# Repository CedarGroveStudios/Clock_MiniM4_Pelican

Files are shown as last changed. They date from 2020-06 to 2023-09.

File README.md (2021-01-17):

# Clock_MiniM4_Pelican (Clock Minima)
## _A minimal but large clock in a Pelican 1040 Micro Case with CircuitPython_

The Clock_MiniM4 is an RTC-based minimal LED display clock implementation inspired by John Park's MetroMinimalist Clock design. The clock uses custom CircuitPython libraries __CedarGroveStudios/Unit_Converter__ for automatic Daylight Saving Time (DTS) and __CedarGroveStudios/Clock_Builder__ for display and user interface functions.

Caution: Under elevated temperature conditions, the sealed Pelican case may not sufficiently dissipate the heat from the clock electronics. A test of the internal operating temperature measured 80F (27C) when interior room temperature was nominally 77F (25C). If the clock will be operated in warmer environments, it is recommended that some holes be drilled into the case to allow air flow.

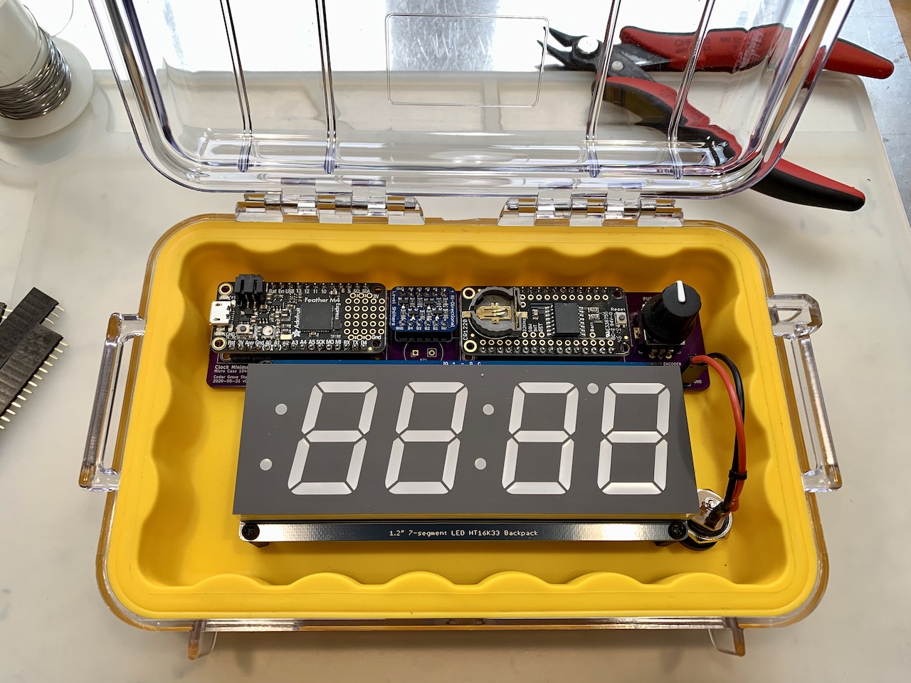
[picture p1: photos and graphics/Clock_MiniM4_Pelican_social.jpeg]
Clock_MiniM4

Photo 1. During assembly.

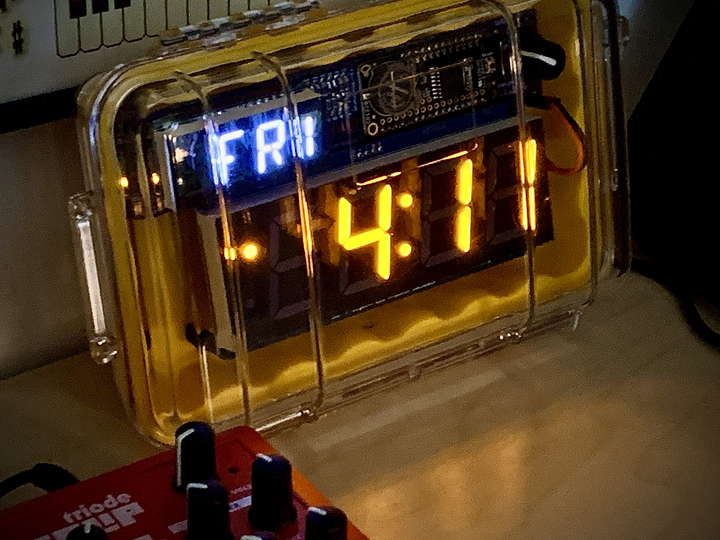
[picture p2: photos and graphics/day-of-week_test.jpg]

Photo 2. Test of auxilliary day-of-week display.



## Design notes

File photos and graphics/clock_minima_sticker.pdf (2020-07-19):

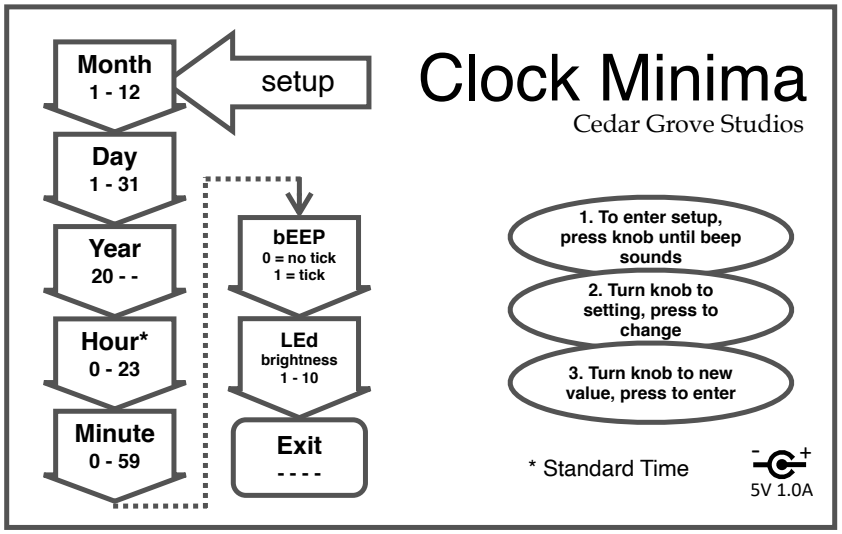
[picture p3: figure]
Clock Minima; Cedar Grove Studios; 1. To enter setup, press knob until beep sounds; 2. Turn knob to setting, press to change; 3. Turn knob to new value, press to enter; setup; Exit; LEd brightness 1 - 10; bEEP 0 = no tick 1 = tick; Minute 0 - 59; Hour*; Year 20 - -; Day; Month; * Standard Time

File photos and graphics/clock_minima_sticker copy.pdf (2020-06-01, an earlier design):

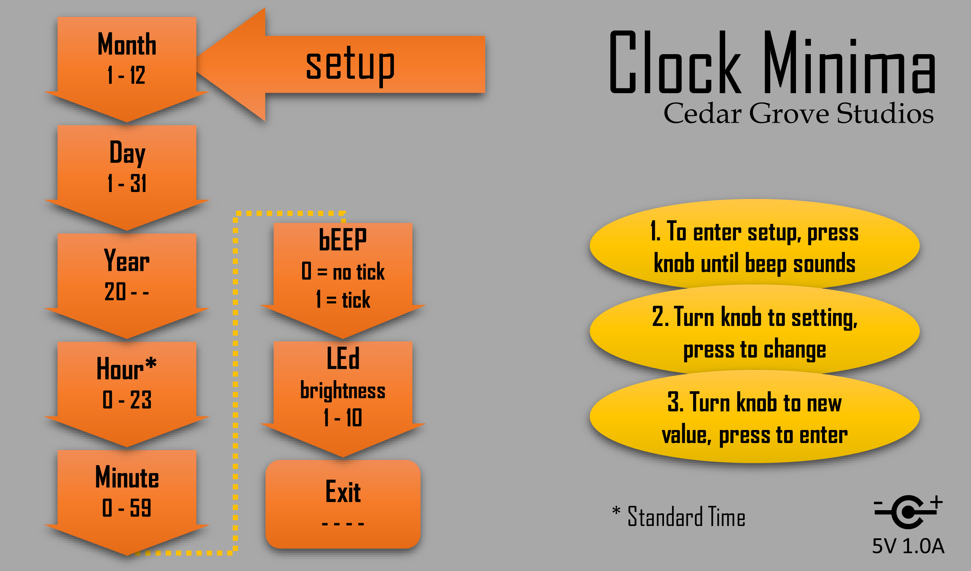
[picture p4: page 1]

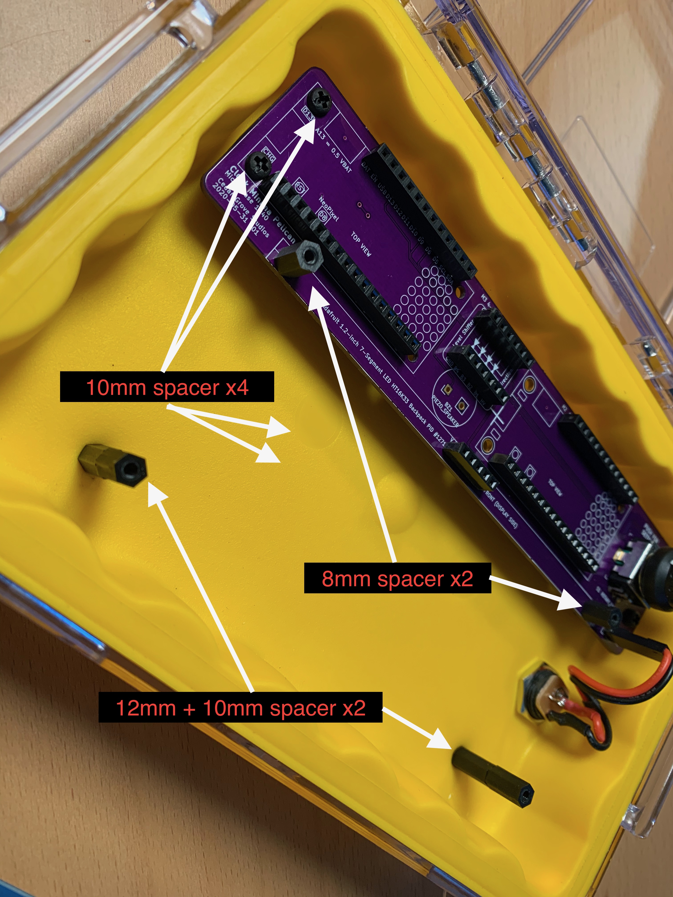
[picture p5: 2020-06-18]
photos and graphics/IMG_0296 - annotated.jpg

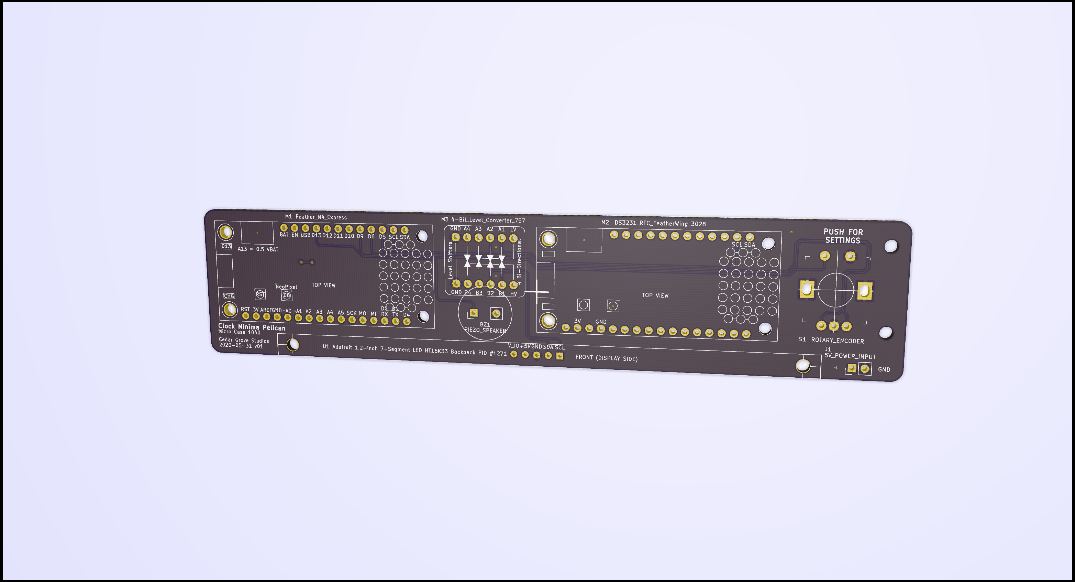
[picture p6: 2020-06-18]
PCB/Clock_MiniM4_Pelican.png

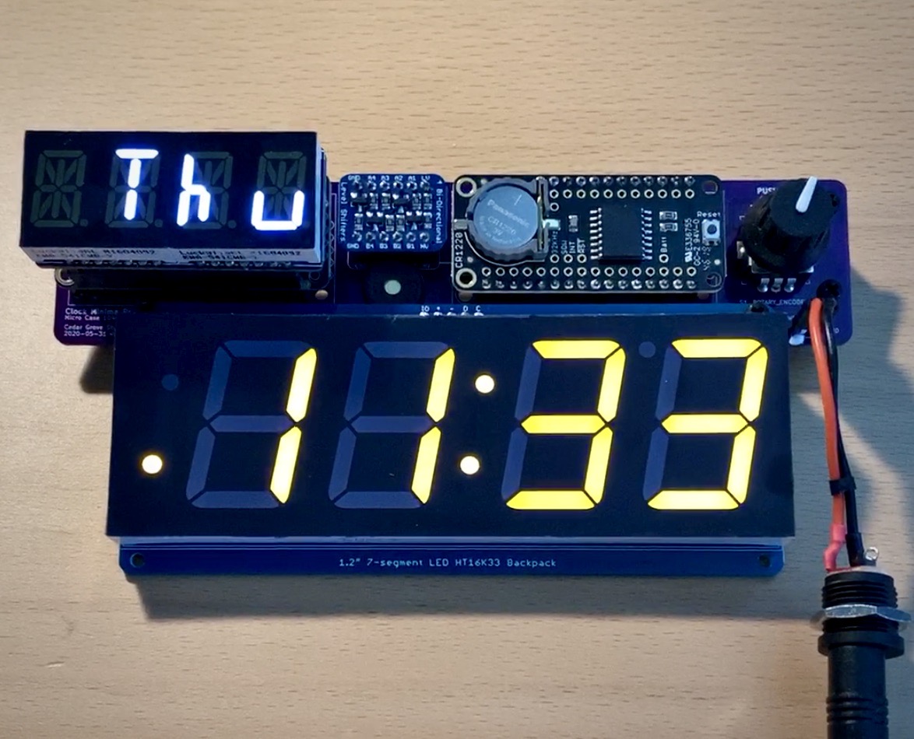
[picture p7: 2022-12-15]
photos and graphics/Screen Shot 2020-07-23 at 3.09.02 PM.jpeg

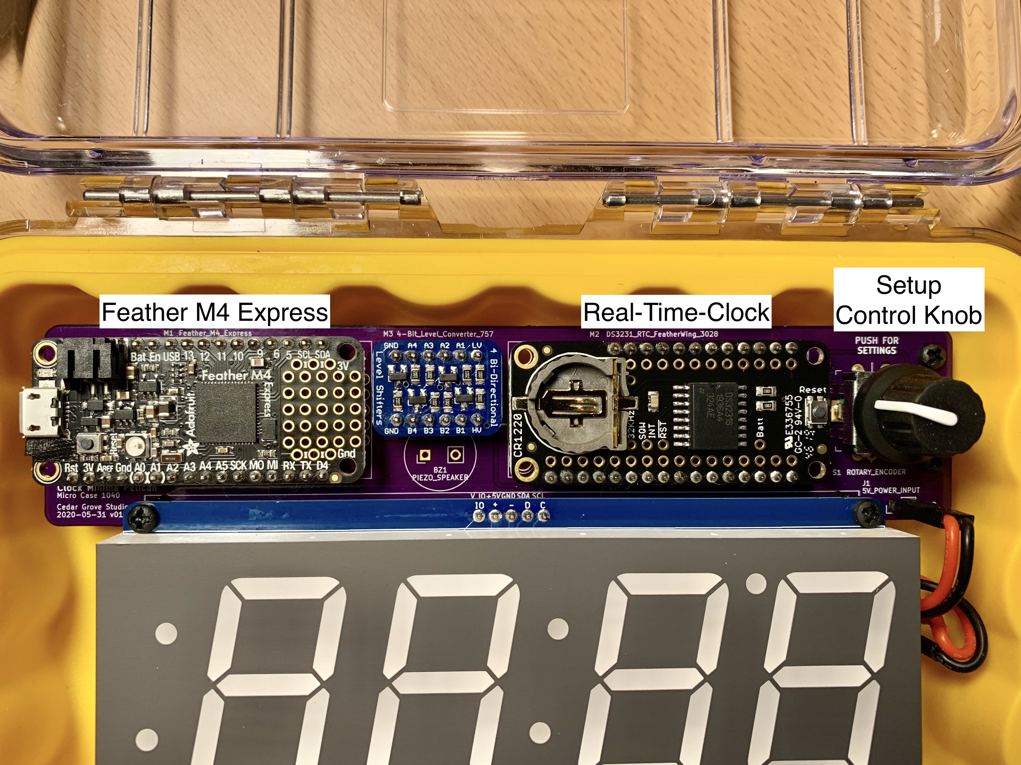
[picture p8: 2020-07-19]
photos and graphics/IMG_0295 annotated.jpg

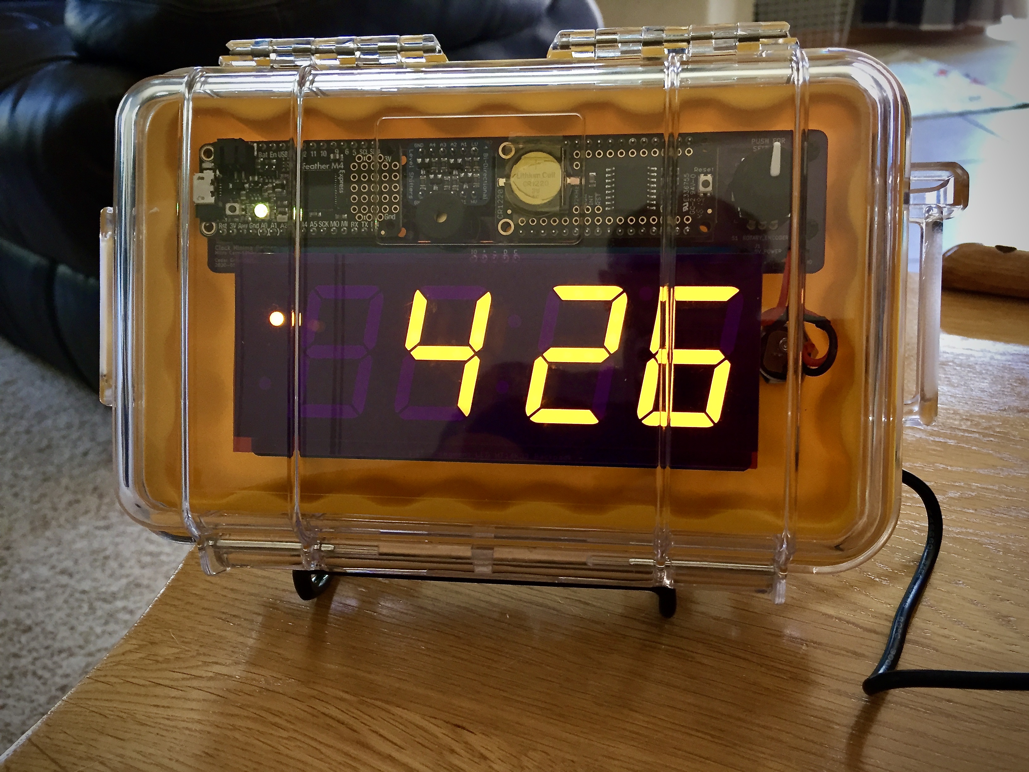
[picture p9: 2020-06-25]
photos and graphics/Clock_MiniM4_Pelican_Spokane.jpeg

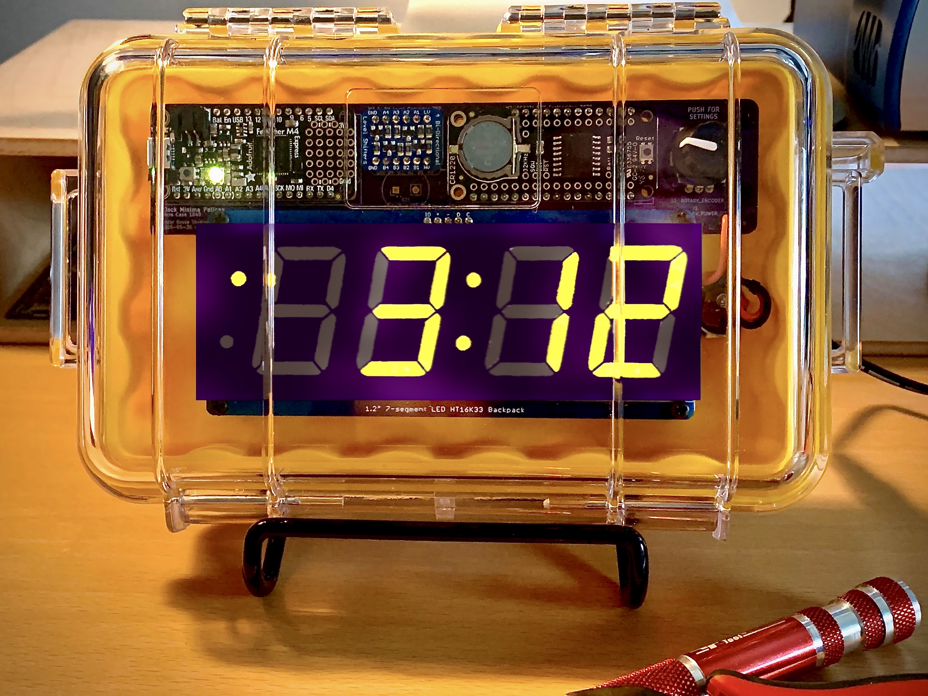
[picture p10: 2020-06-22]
photos and graphics/Clock_MiniM4_Pelican_glamour.jpeg

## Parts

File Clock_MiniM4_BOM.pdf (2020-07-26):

### Bill Of Materials

Qty | Designation | Description | Adafruit | | Digikey | Notes
1 | M1 | Feather M4 Express | PID 3857 | https://www.adafruit.com/product/3857 (https://www.adafruit.com/product/3857) | https://www.digikey.com/products/en?mpart=3857&v=1528 (https://www.digikey.com/products/en?mpart=3857&v=1528)
1 | M2 | DS3231 Precision RTC FeatherWing | PID 3028 | https://www.adafruit.com/product/3028 (https://www.adafruit.com/product/3028) | https://www.digikey.com/products/en?mpart=3028&v=1528 (https://www.digikey.com/products/en?mpart=3028&v=1528) | CR1220 battery: https://www.adafruit.com/products/380 | https://www.digikey.com/product-detail/en/panasonic-bsg/CR1220/P033-ND/269740 (https://www.digikey.com/product-detail/en/panasonic-bsg/CR1220/P033-ND/269740)
1 | M3 | 4-channel I2C-safe Bi-directional Logic Level Converter - BSS138 | PID 757 | https://www.adafruit.com/product/757 (https://www.adafruit.com/product/757) | https://www.digikey.com/products/en?mpart=757&v=1528 (https://www.digikey.com/products/en?mpart=757&v=1528)
1 | S1 | Rotary Encoder | PID 377 | https://www.adafruit.com/product/377 (https://www.adafruit.com/product/377) | https://www.digikey.com/products/en?mpart=377&v=1528 (https://www.digikey.com/products/en?mpart=377&v=1528)
1 | BZ1 | Piezo Buzzer - PS1240 | PID 160 | https://www.adafruit.com/product/160 (https://www.adafruit.com/product/160) | https://www.digikey.com/product-detail/en/tdk-corporation/PS1240P02CT3/445-5229-1-ND/2179635 (https://www.digikey.com/product-detail/en/tdk-corporation/PS1240P02CT3/445-5229-1-ND/2179635) | Alternate: https://www.digikey.com/product-detail/en/tdk-corporation/PS1240P02BT/445-2525-1-ND/935930 (https://www.digikey.com/product-detail/en/tdk-corporation/PS1240P02BT/445-2525-1-ND/935930)
1 | U1 | Adafruit 1.2" 4-Digit 7-Segment Display w/I2C Backpack - Yellow | PID 1269 | https://www.adafruit.com/product/1269 (https://www.adafruit.com/product/1269) | https://www.digikey.com/products/en?mpart=1269&v=1528 (https://www.digikey.com/products/en?mpart=1269&v=1528) | LED display with 5-volt power and data interface (I2C)
1 | | Panel Mount 2.1mm DC barrel jack | PID 610 | https://www.adafruit.com/product/610 (https://www.adafruit.com/product/610) | https://www.digikey.com/product-detail/en/schurter-inc/4840-2200/486-3380-ND/1212406 (https://www.digikey.com/product-detail/en/schurter-inc/4840-2200/486-3380-ND/1212406) | 5v power input jack, 2.1mm
2 | | Short Pin Feather Headers | PID 3002 | https://www.adafruit.com/product/3002 (https://www.adafruit.com/product/3002) | | Pin connectors for Feather M4 and RTC FeatherWing
2 | | Short Receptacle Feather Headers | PID 2940 | https://www.adafruit.com/product/2940 (https://www.adafruit.com/product/2940) | | Pin connectors for Feather M4 and RTC Feather Wing
1 | | 36-pin Short Pin Headers | PID 3009 | https://www.adafruit.com/product/3009 (https://www.adafruit.com/product/3009) | | Pin connectors for Level Converter and LED Display
1 | | 36-pin Short Receptacle Headers | PID 3008 | https://www.adafruit.com/product/3008 (https://www.adafruit.com/product/3008) | | Pin connectors for Level Converter and LED Display
1 Black Nylon Screw and Stand-off Set | | – M2.5 Thread | PID 3299 | https://www.adafruit.com/product/3299 (https://www.adafruit.com/product/3299) | | M2.5 screws and standoffs for mounting PCB and display
1 Pelican 1040 Micro Case, Yellow- | | Clear | | | | https://www.amazon.com/Pelican-1040-Micro-Yellow-Clear/dp/B00152PF4I/ref=psdc_3406401_t2_B0029Q7A1K (https://www.amazon.com/Pelican-1040-Micro-Yellow-Clear/dp/B00152PF4I/ref=psdc_3406401_t2_B0029Q7A1K)
1 | | PCB | | | | OSH Park: https://oshpark.com/shared_projects/wLMeJjED (https://oshpark.com/shared_projects/wLMeJjED)
1 5V 2A (2000mA) switching power | | supply - UL Listed | PID 276 | https://www.adafruit.com/product/276 (https://www.adafruit.com/product/276) | https://www.digikey.com/product-detail/en/tensility-international-corp/16-00066/839-1669-ND/10324415 (https://www.digikey.com/product-detail/en/tensility-international-corp/16-00066/839-1669-ND/10324415) | Wall wart with 2.1mm center-positive plug
1 Adjustable Bent-Wire Stand - up to | | 7" Tablets and Small Screens | PID 1679 | https://www.adafruit.com/product/1679 (https://www.adafruit.com/product/1679) | https://www.digikey.com/products/en?mpart=1679&v=1528 (https://www.digikey.com/products/en?mpart=1679&v=1528)

1

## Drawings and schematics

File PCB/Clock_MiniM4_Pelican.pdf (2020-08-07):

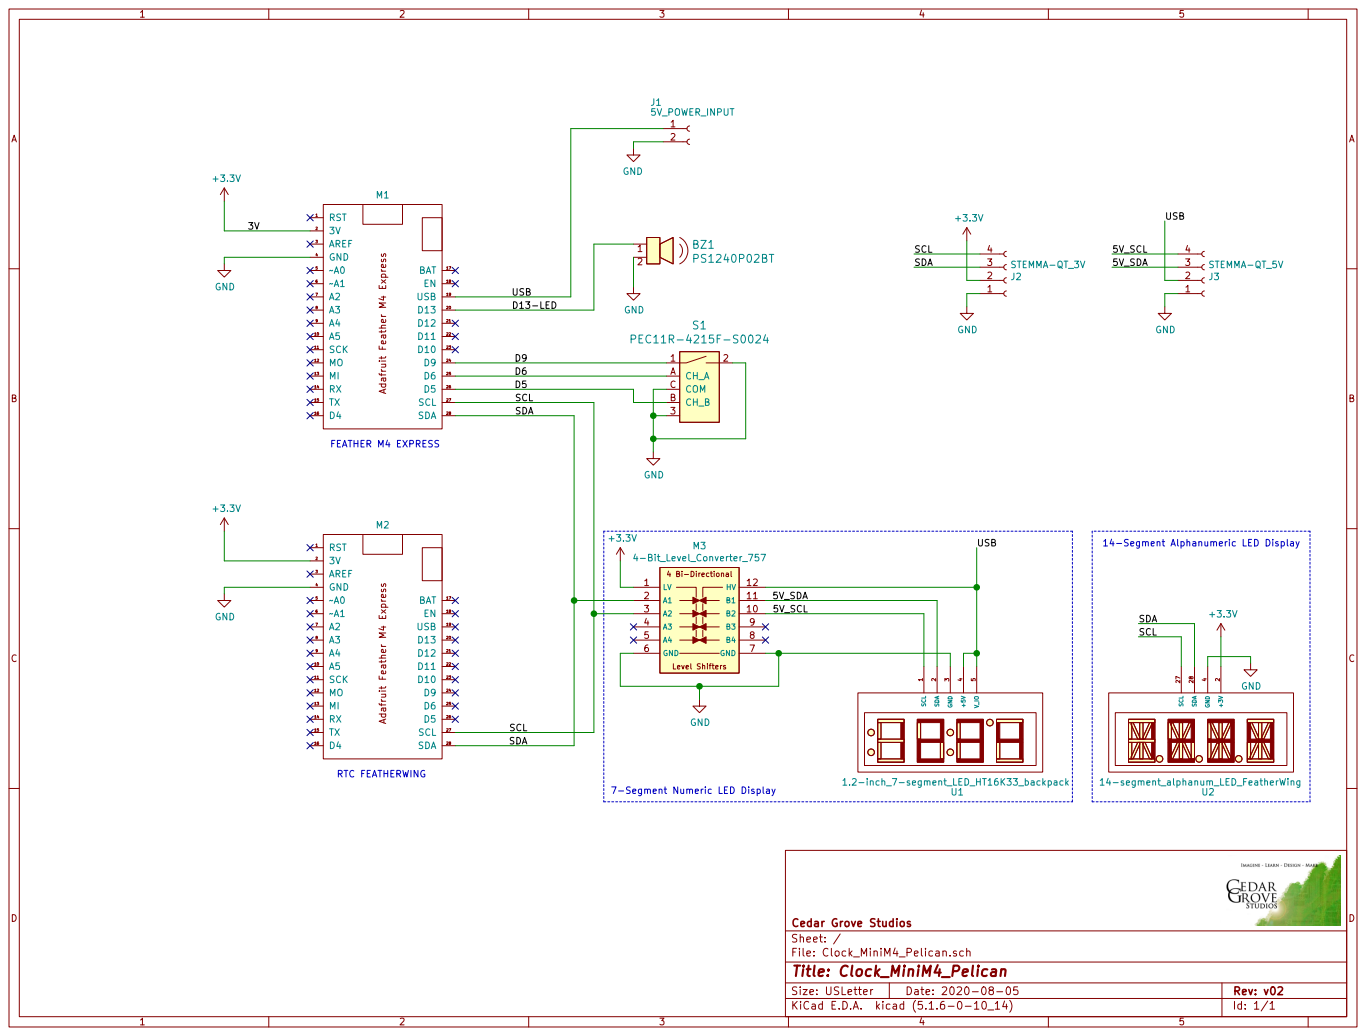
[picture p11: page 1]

7-Segment Numeric LED Display FEATHER M4 EXPRESS RTC FEATHERWING

14-Segment Alphanumeric LED Display

4 Bi-Directional Level Shifters LV 1

File: Clock_MiniM4_Pelican.sch Sheet: / Cedar Grove Studios

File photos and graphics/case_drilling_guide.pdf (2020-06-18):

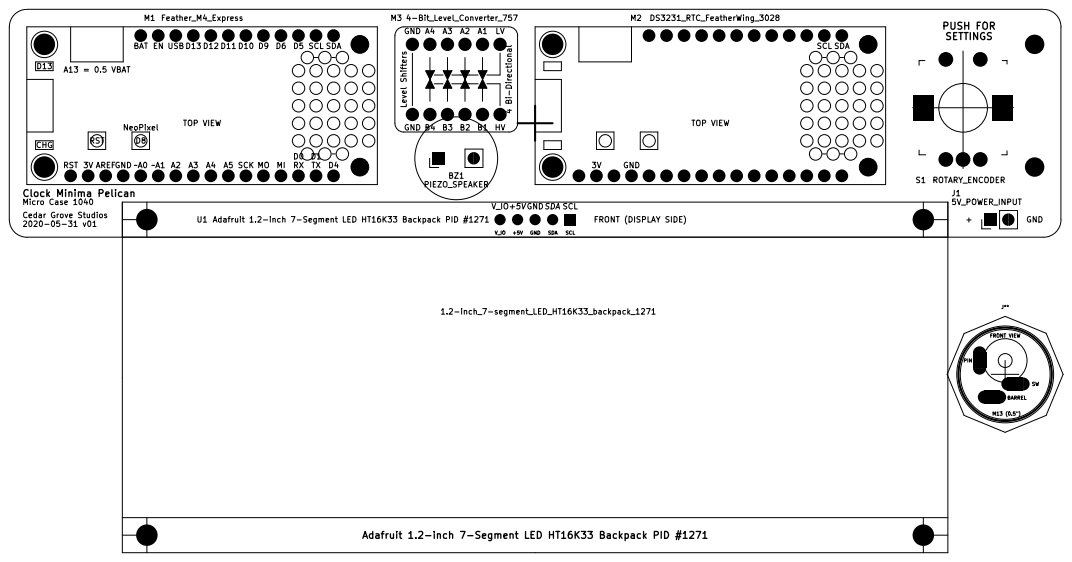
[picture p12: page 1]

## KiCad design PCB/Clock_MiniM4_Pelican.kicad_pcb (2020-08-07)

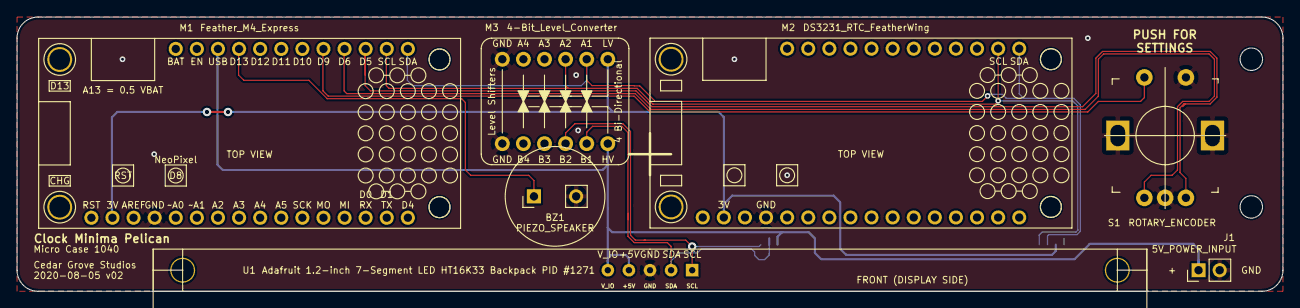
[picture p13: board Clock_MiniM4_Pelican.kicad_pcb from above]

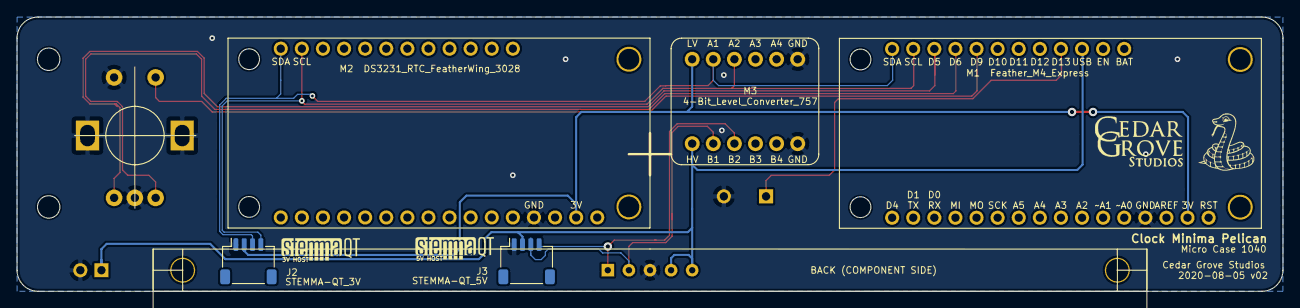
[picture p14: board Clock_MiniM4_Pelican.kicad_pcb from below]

Board: 2 copper layers, 152.4 x 33.0 mm, 10 parts (2 on the bottom side), 11 nets.

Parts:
BZ1: PIEZO_SPEAKER; Socket_Strip_Straight_1x02_Pitch2.54mm
J1: 5V_POWER_INPUT; PinHeader_1x02_P2.54mm_Vertical
J2: STEMMA-QT_3V; JST_SH_SM04B-SRSS-TB_1x04-1MP_P1.00mm_Horizontal
J3: STEMMA-QT_5V; JST_SH_SM04B-SRSS-TB_1x04-1MP_P1.00mm_Horizontal
J**: 2.1mm_THT_DC_panel_power_conn_610
M1: Feather_M4_Express; Adafruit_Feather_M4_Express
M2: DS3231_RTC_FeatherWing; Adafruit_Feather_M4_Express
M3: 4-Bit_Level_Converter; 4-Bit_Level_Converter_757
S1: ROTARY_ENCODER; Rotary_Encoder_Switched_PEC11R_mntg_hole
U1: 1.2-inch_7-segment_LED_HT16K33_backpack

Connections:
+3V3: J2.2, M1.2, M2.2, M3.1
/5V_SCL: J3.4, M3.10, U1.1
/5V_SDA: J3.3, M3.11, U1.2
/D5: M1.26, S1.B
/D6: M1.25, S1.A
/D9: M1.24, S1.1
/D13-LED: BZ1.1, M1.20
/SCL: J2.4, M1.27, M2.27, M3.3
/SDA: J2.3, M1.28, M2.28, M3.2
/USB: J1.1, J3.2, M1.19, M3.12, U1.4, U1.5
GND: BZ1.2, J1.2, J2.1, J3.1, M1.4, M2.4, M3.6, M3.7, S1.2, S1.3, S1.C, U1.3

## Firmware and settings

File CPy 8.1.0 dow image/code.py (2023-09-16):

# clock_miniM4_bigLED.py  2020-07-05_v01)
# Cedar Grove Studios
# for "BIG" 2.1-inch LED display and rotary encoder time setter
# and 14x4 display
# uses cedargrove_unit_converter library
# uses cedargrove_clock_builder library (display, set_time, chime)

import time
import board
import neopixel as neo  # Feather M4
from   simpleio import map_range, tone
import adafruit_ds3231
from   analogio import AnalogIn
from   cedargrove_unit_converter.chronos              import adjust_dst
from   cedargrove_clock_builder.repl_display          import ReplDisplay
from   cedargrove_clock_builder.bigled_7x4_display    import BigLed7x4Display   # 7-segment LED
from   cedargrove_clock_builder.led_14x4_display_dow  import Led14x4DisplayDOW  # 14-segment LED

i2c = board.I2C()
ds3231 = adafruit_ds3231.DS3231(i2c)

# Feather M4 battery monitor and piezo
batt = AnalogIn(board.VOLTAGE_MONITOR)

# Feather M4 NeoPixel, purple start-up indicator
pixel = neo.NeoPixel(board.NEOPIXEL,1, brightness=0.01, auto_write=False)
pixel[0] = (200, 0, 200)
pixel.write()
time.sleep(0.1)

print("Battery: {:01.2f} volts".format((batt.value / 65520) * 6.6))

from Clock_Minima_Pelican_config import *
"""
# Typical contents of config file:
### CONFIGURATION ###
clock_display  = ["big_led", "repl"]  # List of active display(s)
clock_zone     = "Pacific"  # Name of local time zone
clock_24_hour  = False      # 24-hour clock = True; 12-hour AM/PM = False
clock_auto_dst = True       # Automatic US DST = True
clock_sound    = False      # Sound is active = True
clock_tick     = True       # One-second tick sound
clock_bright   = 1.0        # Display brightness; 0 (low) to 1.0 (high)
"""

### Instatiate displays

#  4-digit 7-segment LED display
led_disp  = BigLed7x4Display(clock_zone, clock_24_hour, clock_auto_dst,
                          clock_sound, clock_bright, debug=False, address=0x70)

#  4-digit 14-segment LED alphanumeric display
alpha_led_disp  = Led14x4DisplayDOW(clock_zone, clock_24_hour, clock_auto_dst,
                          clock_sound, clock_bright, debug=False, address=0x71)

#  REPL display
repl_disp = ReplDisplay(clock_zone, clock_24_hour, clock_auto_dst,
                        clock_sound, debug=False)

### Instatiate time setter
# (none)

### Instatiate chimes
# (none)

### HELPERS ###

# Manually set time upon RTC power failure
if ds3231.lost_power:
    print("--RTC POWER FAILURE--")
    # Set time with REPL
    # ds3231.datetime = repl_disp.set_datetime()

    # Set time with LED with rotary encoder
    led_disp.alert("----")

min_flag = half_flag = hour_flag = False

# initiate display contents

# Check datetime and adjust if DST
if clock_auto_dst:             # read the RTC and adjust for DST
    current, is_dst = adjust_dst(ds3231.datetime)
else:
    current = ds3231.datetime  # otherwise, just read the RTC
    is_dst = False

if "led" or "big_led" in clock_display:
    if "led" in clock_display:
        led_disp.message = "CG MiniM4L CLOCK"
    led_disp.dst = is_dst
    led_disp.show(current)
    alpha_led_disp.show_day_of_week(current)

while True:
    # Check datetime and adjust if DST
    if clock_auto_dst:             # read the RTC and adjust for DST
        current, is_dst = adjust_dst(ds3231.datetime)
    else:
        current = ds3231.datetime  # otherwise, just read the RTC
        is_dst = False

    # update REPL display
    if "repl" in clock_display:
        repl_disp.dst = is_dst
        repl_disp.show(current)

    # update led display
    if "led" or "big_led" in clock_display:
        led_disp.colon  = not led_disp.colon

        # Check to see if time was set
        new_xst_datetime, clock_sound, update_flag = led_disp.set_datetime(ds3231.datetime)
        if update_flag:  # If so, update RTC Std Time with new datetime
           ds3231.datetime = new_xst_datetime
           print("RTC time was set")

        led_disp.dst    = is_dst
        led_disp.show(current)  # refresh LED display

        # Refresh FeatherM4 NeoPixel to show "second hand"
        r = int(map_range(current.tm_sec, 0, 45, 255, 100))
        g = int(map_range(current.tm_sec, 15, 59, 100, 255))
        b = int(map_range(current.tm_sec, 55, 59, 100, 255))
        pixel[0] = (r, g, b)
        pixel.write()

    # play tick sound
    if "led" or "big_led" in clock_display:
        if clock_sound and clock_tick:
            led_disp.tick()

    # Do something every minute
    if current.tm_sec == 0 and not min_flag:
        # do something here
        print("every MIN")

        print("Battery: {:01.2f} volts".format((batt.value / 65520) * 6.6))

        # Display date on LED display
        if "led" or "big_led" in clock_display:
            led_disp.dst = is_dst
            alpha_led_disp.brightness = led_disp.brightness
            alpha_led_disp.show_day_of_week(current)
            led_disp.show(current, date=True)

        min_flag = True
    elif current.tm_sec > 0:
        min_flag = False

    # Do something every half-hour
    if current.tm_min == 30 and not half_flag:
        # do something here
        print("every HALF")
        half_flag = True
    elif current.tm_min > 30:
        half_flag = False

    # Do something every hour
    if current.tm_min == 0 and not hour_flag:
        # do something here
        print("every HOUR")
        hour_flag = True
    elif current.tm_min > 0:
        hour_flag = False

    # wait a second before looping
    prev_sec = current.tm_sec
    while current.tm_sec == prev_sec:  # wait a second before looping
        current = ds3231.datetime

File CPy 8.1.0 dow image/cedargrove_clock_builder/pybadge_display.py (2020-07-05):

# pybadge_display.py
# 2020-03-21 Cedar Grove Studios

import time
import board
import displayio
from   adafruit_display_text.label import Label
from   adafruit_bitmap_font        import bitmap_font
import adafruit_imageload
from   adafruit_pybadger import pybadger
from   simpleio                    import map_range

class PyBadgeDisplay:

    def __init__(self, timezone="Pacific", hour_24=False, auto_dst=True,
                 sound=False, brightness=1.0, debug=False):
        # Input parameters
        self._timezone   = timezone
        self._hour_24_12 = hour_24
        self._dst        = False
        self._auto_dst   = auto_dst
        self._sound      = sound
        self._brightness = brightness

        # Other parameters
        self._message     = "PyBadge Clock"
        self._colon       = True
        self._batt_level  = 0   # Default battery level
        self._label_edits = []  # label edit attributes
        self._label_restore_color = []  # for restoring text color values

        self._weekday = ["Mon", "Tue", "Wed", "Thu", "Fri", "Sat", "Sun"]
        self._month   = ["Jan", "Feb", "Mar", "Apr", "May", "Jun", "Jul", "Aug",
                         "Sep", "Oct", "Nov", "Dec"]

        # Load the text font from the fonts folder
        self._font_0 = bitmap_font.load_font("/fonts/OpenSans-9.bdf")
        self._font_1 = bitmap_font.load_font("/fonts/Helvetica-Bold-36.bdf")

        # Instantiate PyBadger instance
        self.panel = pybadger
        self.panel._neopixels.brightness = 0.1  # Set default NeoPixel brightness
        self.panel.pixels.fill(0x000000)        # Clear all NeoPixels
        self.panel.play_tone(440, 0.1)          # A4 welcome tone

        # The board's integral display size and element size
        WIDTH  = board.DISPLAY.width   # 160 for PyGamer and PyBadge
        HEIGHT = board.DISPLAY.height  # 128 for PyGamer and PyBadge
        ELEMENT_SIZE = WIDTH // 4  # Size of element_grid blocks in pixels
        board.DISPLAY.brightness = self._brightness

        # Default colors
        self.BLACK   = 0x000000
        self.RED     = 0xFF0000
        self.ORANGE  = 0xFF8811
        self.YELLOW  = 0xFFFF00
        self.GREEN   = 0x00FF00
        self.CYAN    = 0x00FFFF
        self.BLUE    = 0x0000FF
        self.LT_BLUE = 0x000044
        self.VIOLET  = 0x9900FF
        self.DK_VIO  = 0x110022
        self.WHITE   = 0xFFFFFF
        self.GRAY    = 0x444455

        ### Define the display group ###
        self._image_group = displayio.Group(max_size=15)

        # Create a background color fill layer; image_group[0]
        self._color_bitmap = displayio.Bitmap(WIDTH, HEIGHT, 1)
        self._color_palette = displayio.Palette(1)
        self._color_palette[0] = self.DK_VIO
        self._background = displayio.TileGrid(self._color_bitmap,
                                              pixel_shader=self._color_palette,
                                              x=0, y=0)
        self._image_group.append(self._background)
        self._label_restore_color.append(self.DK_VIO)
        self._label_edits.append(None)

        # Battery indicator tile grid; image_group[1]
        self._sprite_sheet, self._palette = adafruit_imageload.load("/cedargrove_clock_builder/batt_sprite_sheet.bmp",
                                                                    bitmap=displayio.Bitmap,
                                                                    palette=displayio.Palette)
        self._batt_icon = displayio.TileGrid(self._sprite_sheet,
                                             pixel_shader=self._palette,
                                             width = 1, height = 1,
                                             tile_width = 16, tile_height = 16)
        self._batt_icon.x = WIDTH - 16
        self._batt_icon.y = 1
        self._image_group.append(self._batt_icon)
        self._label_restore_color.append(self.BLACK)
        self._label_edits.append(None)

        ### Define labels and values using element grid coordinates
        # Colon; image_group[2]
        self._clock_digits_colon = Label(self._font_1, text=":",
                                         color=self.WHITE, max_glyphs=1)
        self._clock_digits_colon.x = 62
        self._clock_digits_colon.y = (HEIGHT // 2) + 10 - 3
        self._image_group.append(self._clock_digits_colon)
        self._label_restore_color.append(self._clock_digits_colon.color)
        self._label_edits.append(None)

        # Weekday; image_group[3]
        self._clock_wday = Label(self._font_0, text="---",
                                 color=self.YELLOW, max_glyphs=3)
        self._clock_wday.x = 21
        self._clock_wday.y = 40
        self._image_group.append(self._clock_wday)
        self._label_restore_color.append(self._clock_wday.color)
        self._label_edits.append(None)

        # Comma for Month Day (date); image_group[4]
        self._clock_comma = Label(self._font_0, text=",",
                                  color=self.YELLOW, max_glyphs=1)
        self._clock_comma.x = 99
        self._clock_comma.y = 40
        self._image_group.append(self._clock_comma)
        self._label_restore_color.append(self._clock_comma.color)
        self._label_edits.append(None)

        # AM/PM indicator; image_group[5]
        self._clock_ampm = Label(self._font_0, text="--",
                                 color=self.WHITE, max_glyphs=2)
        self._clock_ampm.x = 120
        self._clock_ampm.y = (HEIGHT // 2) + 10 - 8
        self._image_group.append(self._clock_ampm)
        self._label_restore_color.append(self._clock_ampm.color)
        self._label_edits.append(None)

        # Time Zone indicator; image_group[6]
        self._clock_dst = Label(self._font_0, text="---",
                                color=self.VIOLET, max_glyphs=3)
        self._clock_dst.x = 120
        self._clock_dst.y = (HEIGHT // 2) + 10 + 8
        self._image_group.append(self._clock_dst)
        self._label_restore_color.append(self._clock_dst.color)
        self._label_edits.append(None)

        # Sound indicator; image_group[7]
        self._clock_sound = Label(self._font_0, text="-----",
                                  color=self.VIOLET, max_glyphs=5)
        self._clock_sound.x = 5
        self._clock_sound.y = HEIGHT - 8
        self._image_group.append(self._clock_sound)
        self._label_restore_color.append(self._clock_sound.color)
        self._label_edits.append(("boolean", 0, 1))

        # Automatic DST indicator; image_group[8]
        self._clock_auto_dst = Label(self._font_0, text="-------",
                                     color=self.VIOLET, max_glyphs=7)
        self._clock_auto_dst.x = 104
        self._clock_auto_dst.y = HEIGHT - 8
        self._image_group.append(self._clock_auto_dst)
        self._label_restore_color.append(self._clock_auto_dst.color)
        self._label_edits.append(("boolean", 0 , 1))
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

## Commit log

2020-06-01 initial repo load
    [Clock_MiniM4_Pelican-B_Cu.gbl, Clock_MiniM4_Pelican-B_Mask.gbs, Clock_MiniM4_Pelican-B_Paste.gbp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]
2020-06-02 update PCB design
    [Clock_MiniM4_Pelican-B_Cu.gbl, Clock_MiniM4_Pelican-B_Mask.gbs, Clock_MiniM4_Pelican-B_Paste.gbp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]
2020-06-04 update schematic drawing
    [Clock_MiniM4_Pelican.sch]
2020-06-18 update BOM
2020-07-25 update PCB; display bright in param file
    [Clock_MiniM4_Pelican.kicad_pcb, Clock_MiniM4_Pelican.sch]
2020-07-26 update CPy 5.3 image and BOM
2020-08-05 Update new PCB design - fix STEMMA-QT pinout
    [Clock_MiniM4_Pelican-B_Cu.gbl, Clock_MiniM4_Pelican-B_Mask.gbs, Clock_MiniM4_Pelican-B_Paste.gbp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]
2020-08-07 update pcb
    [Clock_MiniM4_Pelican-B_Cu.gbl, Clock_MiniM4_Pelican-B_Mask.gbs, Clock_MiniM4_Pelican-B_Paste.gbp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]
